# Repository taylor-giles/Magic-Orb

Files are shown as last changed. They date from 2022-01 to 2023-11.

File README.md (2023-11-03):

# Magic Crystal Orb
Collaborators/Wizards - 
[Taylor Giles](https://taylorgiles.me), [Anthony Piccinone](https://piccinone.com), [Joseph Romano](https://josephromanodesign.com/)

## Summary
A set of three ESP8266-powered crystal orbs that light up together whenever a fellow "wizard" activates one. Each orb in the set is assigned a color - either red, green, or blue - and when an orb is activated, its color is added to the mixture, resulting in a mystical white when all three wizards are present at the same time.

## Usage
### Connect to the Internet
The ESP8266 boards will remember the last WiFi network they were connected to, so they can connect automatically. However, if connection fails (or the network is no longer present), then the device will enter a configuration mode.
The light will flash, indicating that the local AP and configuration page have been activated. Connect to the generated WiFi network using another device, and navigate
to ``192.168.4.1``. Enter the credentials for the desired WiFi network, and the ESP8266 will reboot to connect to the chosen network.

### Activate the Orb
To activate a connected orb, simply place your hand on it, and the magic crystal will add your color to all the other connected orbs. When any of the connected orbs
are activated, your orb will change color to match.

## Build Instructions
### Materials
* ESP8266 NodeMCU
* RGB LED
* PIR Motion Sensor
* Frosted glass/acrylic orb
* Base and support (3D-printed: see ``Models`` folder)

### Instructions
1. Connect the hardware according to the given schematic
1. Secure the PIR Sensor to the top of the support and secure the support to the base
(Note: The sensor should just touch the inside of the orb when it is placed into the base)
1. For each orb, select a color. Connect NodeMCU pin ``D5`` to ``GND`` to select green; ``D6`` to ``GND`` for blue; leave both ungrounded for red
1. Make a [Firebase](https://firebase.google.com/) project with a Realtime Database
1. Install the [Arduino IDE](https://www.arduino.cc/en/software)
1. [Install the ESP8266 addon for Arduino IDE](https://randomnerdtutorials.com/how-to-install-esp8266-board-arduino-ide/)
1. Install the following libraries: [WiFiManager](https://github.com/tzapu/WiFiManager) & [Firebase ESP Client](https://github.com/mobizt/Firebase-ESP-Client)
1. Open ``Magic-Orb.ino`` and fill in the ``WM_SSID``, ``WM_PASSWORD``, ``API_KEY``, and ``DATABASE_URL`` (note that the last two are from Firebase)
1. Upload the sketch to the ESP8266 board
1. Refer to "Usage" and enjoy :)

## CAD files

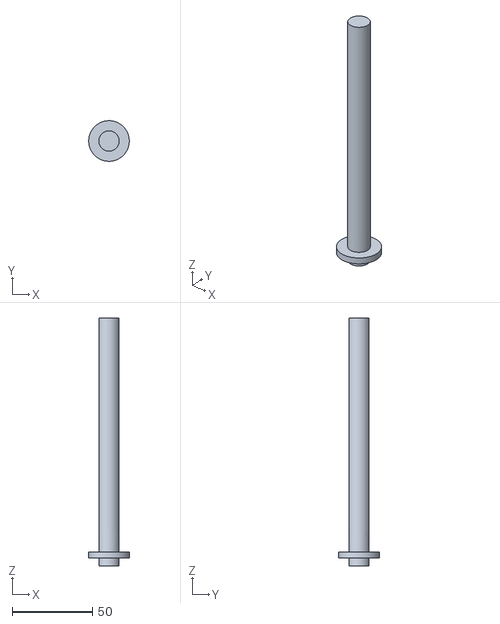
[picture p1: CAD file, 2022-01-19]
Models/Pole.stl
25.4 x 25.4 x 154.9

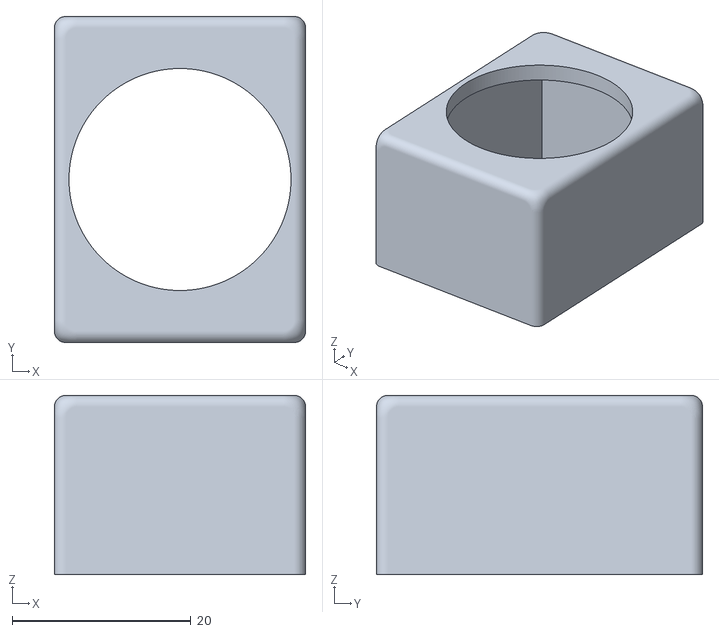
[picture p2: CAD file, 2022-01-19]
Models/SensorHousing.stl
28.1 x 36.5 x 20.1

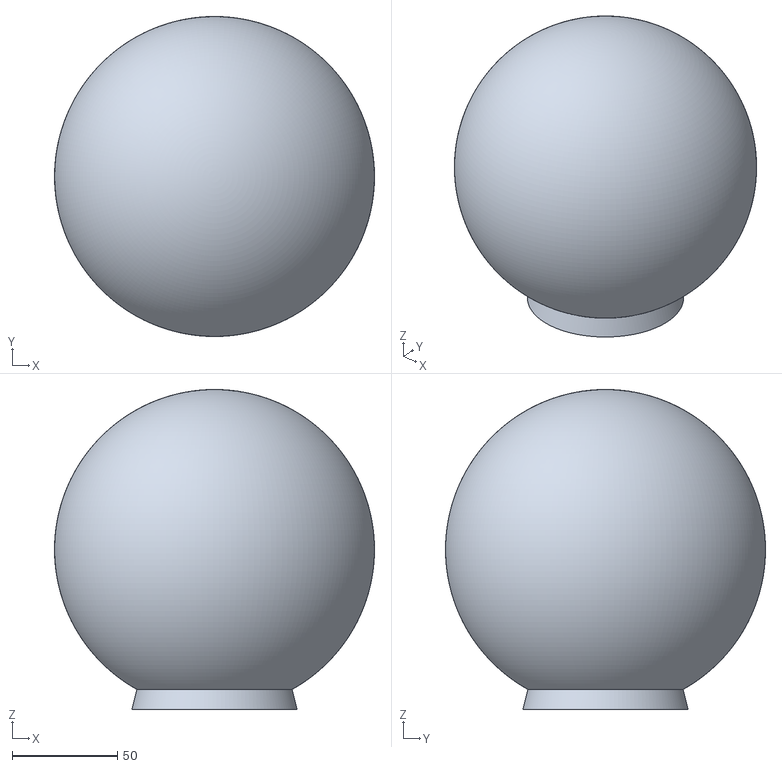
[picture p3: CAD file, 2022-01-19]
Models/Orb.stl
152.4 x 152.4 x 152.4

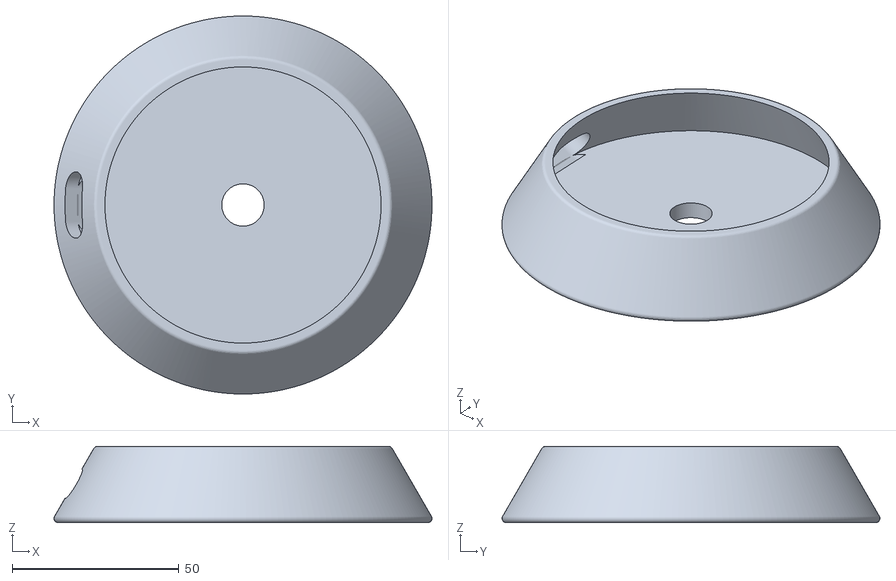
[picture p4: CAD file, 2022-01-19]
Models/BaseLegless.stl
113.3 x 113.3 x 22.9

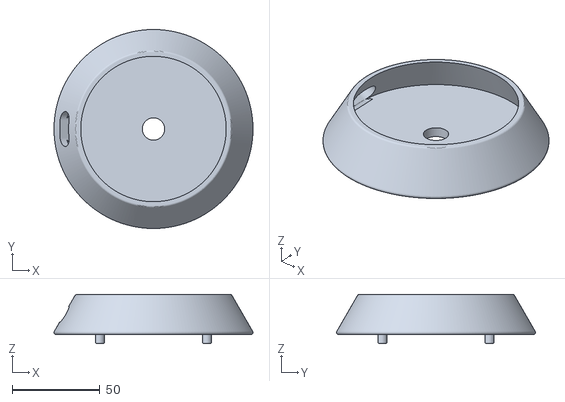
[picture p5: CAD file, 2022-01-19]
Models/Base.stl
113.3 x 113.3 x 27.9

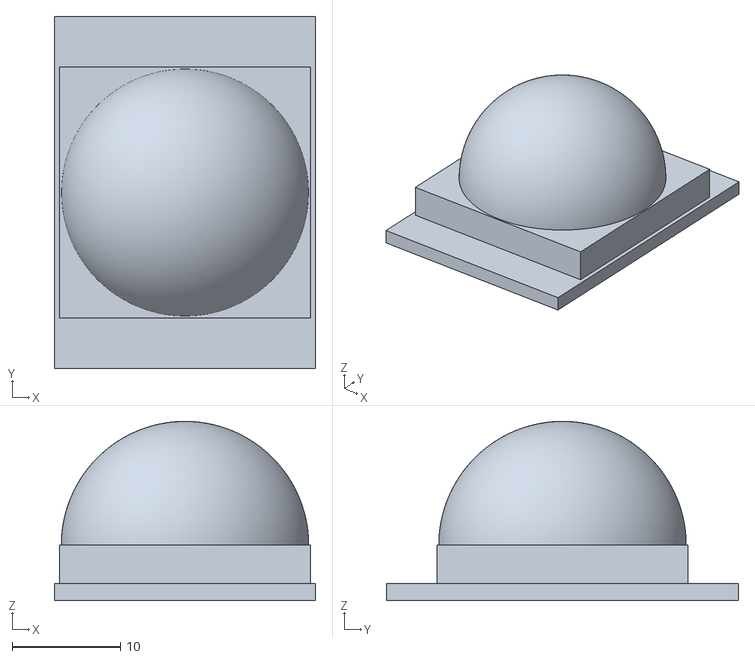
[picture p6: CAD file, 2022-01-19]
Models/MotionSensor.stl
24.1 x 32.5 x 16.6

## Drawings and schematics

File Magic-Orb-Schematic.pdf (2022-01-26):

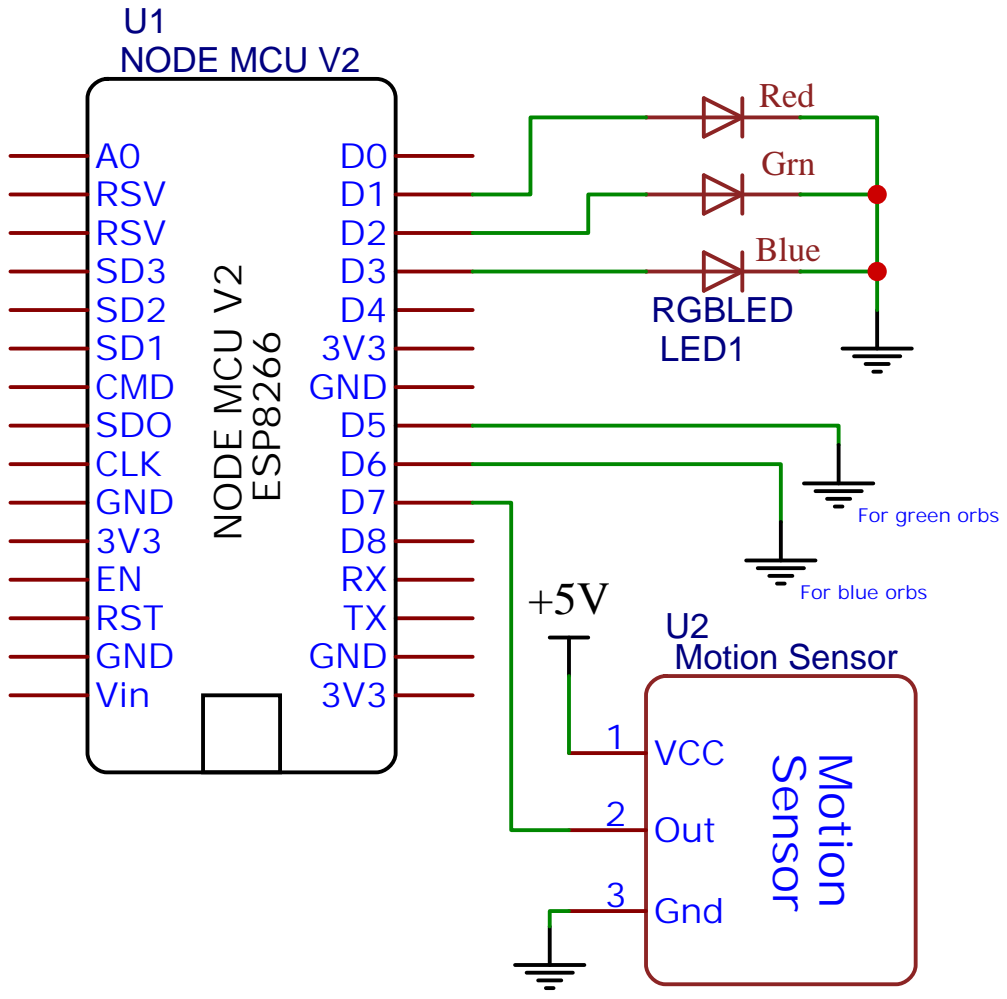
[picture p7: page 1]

Drawn By: Taylor Giles

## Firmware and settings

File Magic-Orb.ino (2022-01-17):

/*
 * Magic Orbs - A set of IoT orbs that change color when they are pondered.
 * Connected using Firebase Realtime Database
 * 
 * Using the Firebase ESP8266 tutorial by 
 * Rui Santos https://RandomNerdTutorials.com/esp8266-nodemcu-firebase-realtime-database/
 * 
 * @author Taylor Giles
*/

#include <Arduino.h>
#if defined(ESP32)
  #include <WiFi.h>
#elif defined(ESP8266)
  #include <ESP8266WiFi.h>
#endif
#include <Firebase_ESP_Client.h>

//Provide the token generation process info.
#include "addons/TokenHelper.h"

//Provide the RTDB payload printing info and other helper functions.
#include "addons/RTDBHelper.h"

//Library for getting WiFi credentials automatically from AP webpage
#include <WiFiManager.h>

// Credentials for WiFiManager Access Point (for config page)
#define WM_SSID "SECRET"
#define WM_PASSWORD "SECRET"

// Firebase API Key (Project Settings -> Web API Key)
#define API_KEY "SECRET"

// URL of the Realtime Database
#define DATABASE_URL "SECRET" 

//Number of millis between updates
#define UPDATE_DELAY 10000

//Min. number of millis between sends 
#define SEND_DELAY 5000

//Duration (in millis) to allow a light to stay on
#define LIGHT_DURATION 120000

//Number of colors
#define NUM_COLORS 3

//Pins
#define RED_PIN 5       //D1
#define GREEN_PIN 4     //D2
#define BLUE_PIN 0      //D3
#define SELECT_GREEN 14 //D5
#define SELECT_BLUE 12  //D6
#define SENSOR_PIN 13   //D7

//Firebase objs
FirebaseData fb_data;
FirebaseAuth fb_auth;
FirebaseConfig fb_config;

//Program values
unsigned long timeLastUpdated = 0;
unsigned long timeLastSent = 0;

//WiFiManager-related values
bool isConnected = false;
unsigned long timeLastBlinked = 0;
bool isBlinkOn = false;
const int BLINK_DELAY = 1000; //ms between blinks

//A struct to store data for each of red, green, and blue
typedef struct color {
  String id;
  long timeLastActivated;
  bool isOn;
  uint8_t pin;
} Color;

//Save the colors as structs for easy access with loops
Color red{"r", 0, false, RED_PIN};
Color green{"g", 0, false, GREEN_PIN};
Color blue{"b", 0, false, BLUE_PIN};
Color colors[3] = {red, green, blue};
Color myColor;

//WiFi Manager
WiFiManager wifiManager;


void setup(){
  //Pin modes
  pinMode(SENSOR_PIN, INPUT);
  pinMode(SELECT_GREEN, INPUT_PULLUP);
  pinMode(SELECT_BLUE, INPUT_PULLUP);
  for(int i = 0; i < 3; i++){
    pinMode(colors[i].pin, OUTPUT);
    digitalWrite(colors[i].pin, LOW);
  }
  Serial.begin(115200);
  Serial.println();

  //Determine which color this orb uses
  myColor = red;
  Serial.print(digitalRead(SELECT_GREEN));
  Serial.println(digitalRead(SELECT_BLUE));
  if(digitalRead(SELECT_GREEN) == LOW){
    myColor = green;
  } else if(digitalRead(SELECT_BLUE) == LOW){
    myColor = blue;
  }
  Serial.print("Chosen color: ");
  Serial.println(myColor.id);

  //Connect to WiFi using saved credentials. If connection fails, open config page with AP
  wifiManager.setConfigPortalBlocking(false);
  isConnected = wifiManager.autoConnect(WM_SSID, WM_PASSWORD);
  if(isConnected){
    //Set up Firebase credentials
    fb_config.api_key = API_KEY; /* Assign the api key (required) */
    fb_config.database_url = DATABASE_URL; /* Assign the RTDB URL (required) */
  
    //Sign in to Firebase
    Serial.println("Signing into Firebase...");
    if (Firebase.signUp(&fb_config, &fb_auth, "", "")){
      Serial.println("Success!");
      /* Assign the callback function for the long running token generation task */
      fb_config.token_status_callback = tokenStatusCallback; //see addons/TokenHelper.h
    
      //Begin Firebase
      Firebase.begin(&fb_config, &fb_auth);
      Firebase.reconnectWiFi(true);
    } else {
      isConnected = false;
      Serial.println("Firebase sign-in failed.");
      Serial.printf("%s\n", fb_config.signer.signupError.message.c_str());
    }
  } else {
    Serial.println("Connection failed.");
    Serial.println("Starting config page with AP...");
  }
}


void loop(){
  if(isConnected){
    //Update if enough time has passed
    if(checkDelay(timeLastUpdated, UPDATE_DELAY)){
      updateDisplay();
    }
  
    //Detect pondering
    if(digitalRead(SENSOR_PIN) == HIGH){
      Serial.println("Motion detected.");
      onPonder();
    }
  
    //Turn off any colors that need to be turned off
    checkColorsForTurnoff();
  } else {
    //WifiManager config portal processing
    if(wifiManager.process()){
      ESP.restart();
    }

    //Blink the red LED
    if(checkDelay(timeLastBlinked, BLINK_DELAY)){
      timeLastBlinked = millis();
      digitalWrite(red.pin, isBlinkOn);
      isBlinkOn = !isBlinkOn;
    }
  }
}


/**
 * Gets updated color values from Firebase and updates the orb's display
 */
void updateDisplay(){
  Serial.print("Updating... ");
  for(int i = 0; i < NUM_COLORS; i++){
    //Get the updated color
    int updatedColor = getColor(colors[i].id);
    Serial.print(colors[i].id);
    Serial.print(updatedColor);
    Serial.print(colors[i].isOn);
    Serial.print(" ");

    //If this color was just turned on and was off before...
    if(updatedColor > 0 && !colors[i].isOn){
      //Update the timeLastActivated
      colors[i].timeLastActivated = millis();

      //Activate the light
      activateColorDisplay(colors[i]);
    }

    //If this color was just turned off and was on before...
    if(updatedColor <= 0 && colors[i].isOn){
      //Deactivate the light
      deactivateColorDisplay(colors[i]);
    }
    
    //Update this color's "isOn" status
    colors[i].isOn = (updatedColor > 0);

    //Ensure display is correct (in case of fade failure (analog issues, etc.))
    digitalWrite(colors[i].pin, colors[i].isOn);
  }
  Serial.println();
  timeLastUpdated = millis();
}


/**
 * Callback for the activation of the orb - 
 * Activates the color of this orb in the database
 */
void onPonder(){
  //Activate this orb's color in the database
  if(setColor(1, myColor.id)){
    //Force an update from database
    updateDisplay();
    Serial.println("Successfully sent color");
  }
}


/**
 * Send the given value for the given color to the database
 * 
 * Returns false on failure or if the appropriate delay has not been satisfied, true otherwise.
 */
bool setColor(int value, String id){
  if(checkDelay(timeLastSent, SEND_DELAY)){
    timeLastSent = millis();
    Serial.print("Sending ");
    Serial.print(id);
    Serial.println(value);
    return (Firebase.RTDB.setInt(&fb_data, "c/" + id, value));
  }
  return false;
}


/**
 * Queries Firebase for the latest value of the specified color
 */
int getColor(String colorId){
  if (Firebase.RTDB.getInt(&fb_data, "/c/" + colorId)) {
    if (fb_data.dataType() == "int") {
      return fb_data.intData();
    }
  }
  return -1;
}


/**
 * Turn off any light that has been on for longer than the specified duration
 */
void checkColorsForTurnoff(){
  for(int i = 0; i < NUM_COLORS; i++){
    if(colors[i].isOn && checkDelay(colors[i].timeLastActivated, LIGHT_DURATION)){
      Serial.print("Turning off ");
      Serial.println(colors[i].id);
      if(setColor(0, colors[i].id)){
        Serial.println("Turnoff successful");
        deactivateColorDisplay(colors[i]);
        colors[i].isOn = false;
      }
    }
  }
}


/**
 * Fades the specified color from "off" to "on"
 */
void activateColorDisplay(Color color){
  for(int i = 0; i < 256; i++){
    analogWrite(color.pin, i);
    delay(1);  //Duration of animation = 256ms
  }
}

/**
 * Fades the specified color from "on" to "off"
 */
void deactivateColorDisplay(Color color){
  for(int i = 255; i >= 0; i--){
    analogWrite(color.pin, i);
    delay(1);  //Duration of animation = 256ms
  }
}


/**
 * Returns true if at least <maxDelay> millis have passed since the 
 * time specified by <startTime>, false otherwise
 */
bool checkDelay(long startTime, long maxDelay){
  return millis() - startTime >= maxDelay;
}

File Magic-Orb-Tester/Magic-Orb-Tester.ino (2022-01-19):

/**
 * Magic Orb testing code
 * Lights will flash R, G, B, W 3times
 * Then will turn white whenever motion is detected
 * 
 * @author Taylor Giles
 */


//Pins
#define RED_PIN 5       //D1
#define GREEN_PIN 4     //D2
#define BLUE_PIN 0      //D3
#define SENSOR_PIN 13   //D7

long lastTime = 0;

void setup() {
  Serial.begin(115200);
  pinMode(SENSOR_PIN, INPUT);
  pinMode(RED_PIN, OUTPUT);
  pinMode(GREEN_PIN, OUTPUT);
  pinMode(BLUE_PIN, OUTPUT);

  //Check lights
  for(int i = 0; i < 3; i++){
    allOff();
    Serial.println("R");
    digitalWrite(RED_PIN, HIGH);
    delay(1000);
    allOff();
    Serial.println("G");
    digitalWrite(GREEN_PIN, HIGH);
    delay(1000);
    allOff();
    Serial.println("B");
    digitalWrite(BLUE_PIN, HIGH);
    delay(1000);
    allOff();
    Serial.println("W");
    digitalWrite(RED_PIN, HIGH);
    digitalWrite(GREEN_PIN, HIGH);
    digitalWrite(BLUE_PIN, HIGH);
    delay(1000);
  }
}

void loop() {
  if(digitalRead(SENSOR_PIN) == HIGH){
    Serial.println("Motion");
    digitalWrite(RED_PIN, HIGH);
    digitalWrite(GREEN_PIN, HIGH);
    digitalWrite(BLUE_PIN, HIGH);
  } else {
    allOff();
  }

}

void allOff(){
  digitalWrite(RED_PIN, LOW);
  digitalWrite(GREEN_PIN, LOW);
  digitalWrite(BLUE_PIN, LOW);
}

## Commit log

2022-01-17 Switch to grounded selector pin output
2022-01-18 Added STL files
    [Base.stl, BaseLegless.stl, MotionSensor.stl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]
2022-01-19 Add schematic
2022-01-26 Updated schematic
